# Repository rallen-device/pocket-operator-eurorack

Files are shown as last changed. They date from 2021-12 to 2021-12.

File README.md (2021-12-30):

# Pocket Operator Eurorack

Hardware for converting a teenage engineering pocket operator to be eurorack compatible.

Slots onto the back of the pocket operator. Requires soldering to the audio jacks + battery connectors.
Splits stereo input + output in two mono channels for each allowing separation of clock + audio.

Fits into a standard eurorack 3U case with width of 14HP.

# Relevant

3D step model of a pocket operator was created for this project. It can be found on grabcad: https://grabcad.com/library/teenage-engineering-pocket-operator-1

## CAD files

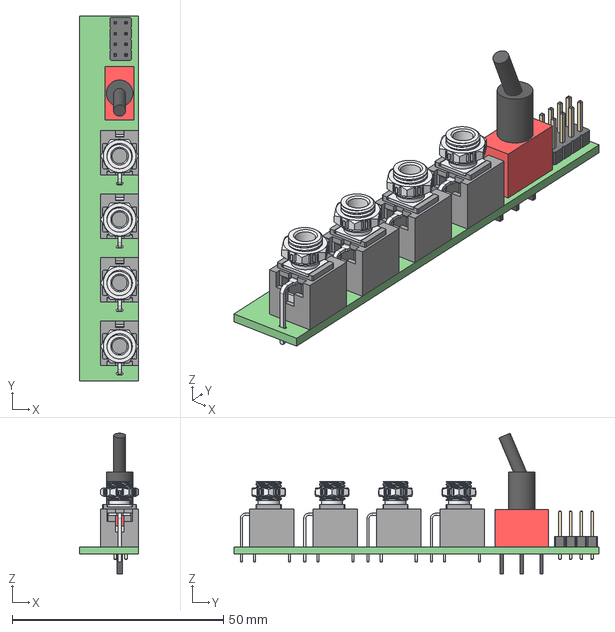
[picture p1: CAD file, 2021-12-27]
pocket-operator-eurorack-connector-board/pocket-operator-eurorack-connector-board.step
14.0 x 86.4 x 33.3 mm

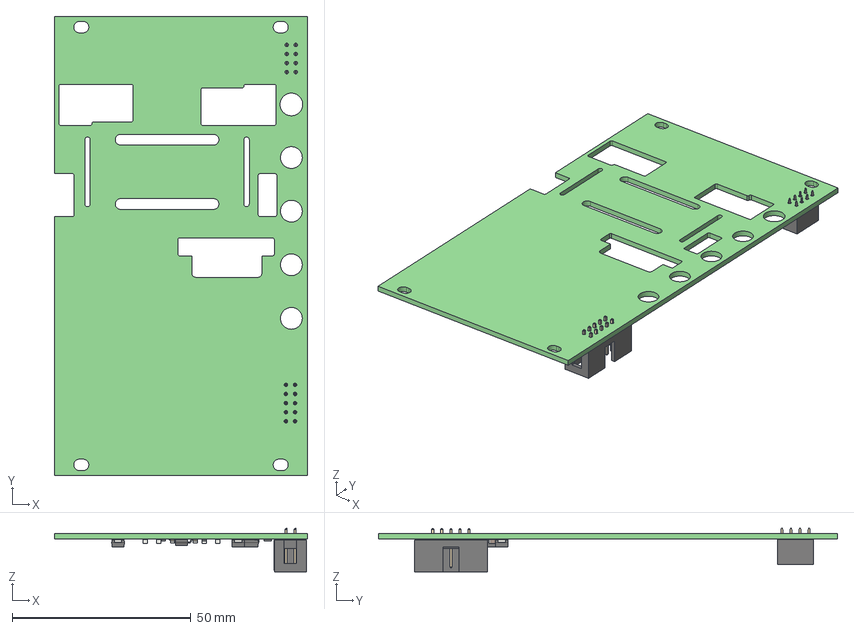
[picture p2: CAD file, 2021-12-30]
pocket-operator-eurorack/pocket-operator-eurorack.step
70.8 x 128.5 x 12.2 mm

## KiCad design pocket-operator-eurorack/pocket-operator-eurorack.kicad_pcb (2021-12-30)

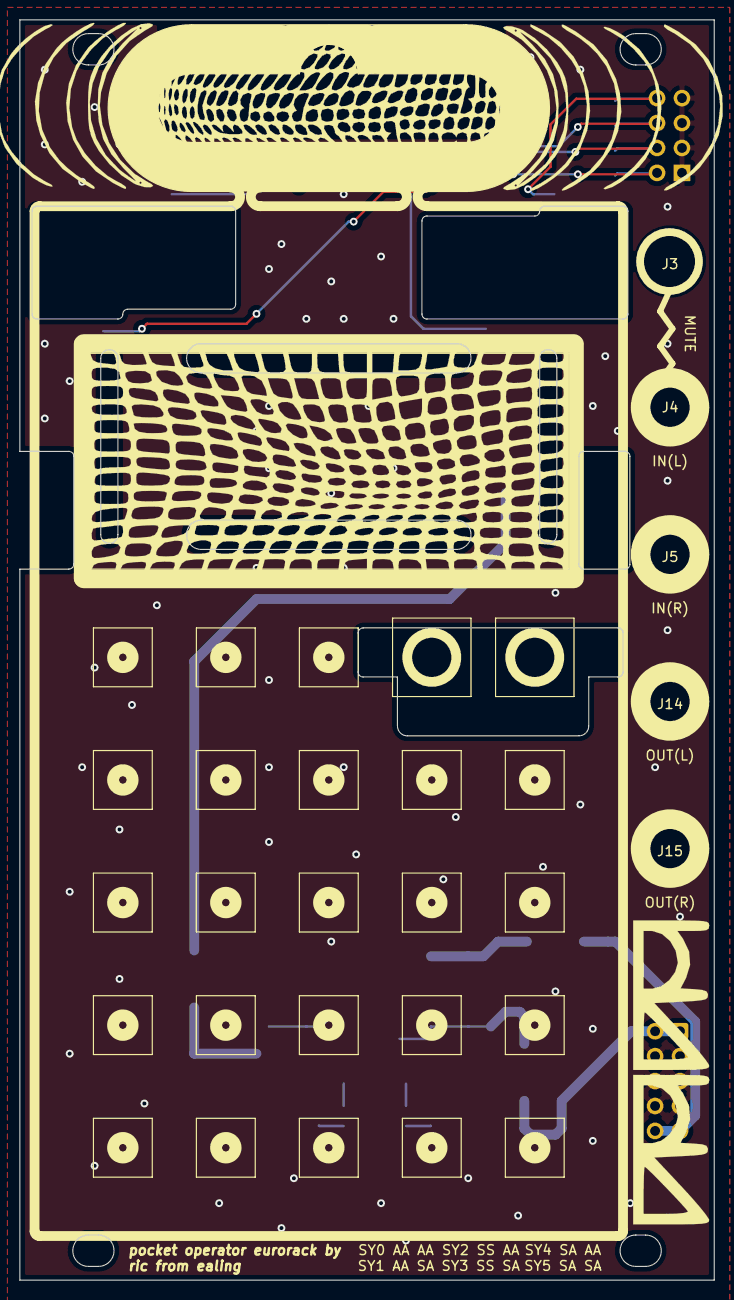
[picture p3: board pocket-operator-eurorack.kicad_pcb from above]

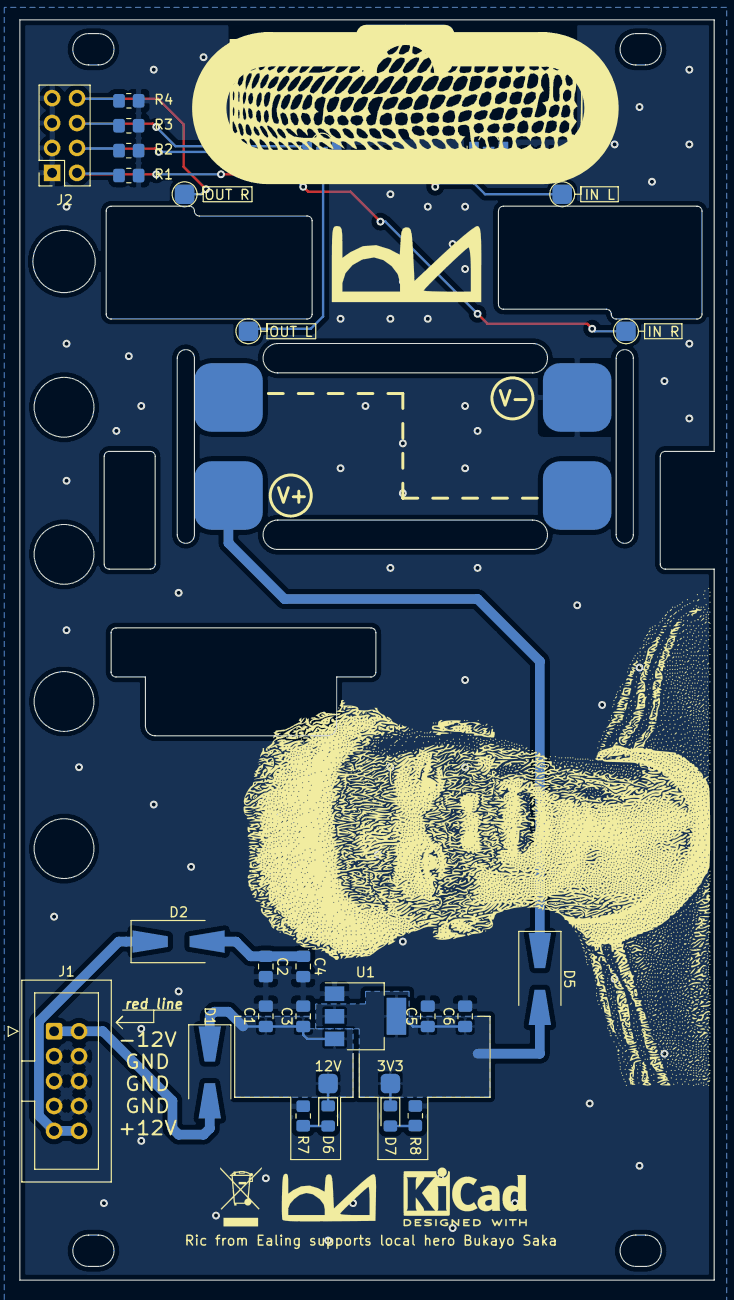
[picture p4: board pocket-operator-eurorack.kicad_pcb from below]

Board: 2 copper layers, 70.8 x 128.5 mm, 39 parts (34 on the bottom side), 15 nets.

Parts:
C1, C2, C3, C4, C5, C6: C; C_0805_2012Metric_Pad1.18x1.45mm_HandSolder
D1, D2, D5: D; D_SMA-SMB_Universal_Handsoldering
D3, D4: LED; LED_Kingbright_APFA3010_3x1.5mm_Horizontal
D6, D7: LED; LED_0805_2012Metric_Pad1.15x1.40mm_HandSolder
J1: Conn_02x05_Odd_Even; IDC-Header_2x05_P2.54mm_Vertical
J2: Conn_02x04_Odd_Even; PinSocket_2x04_P2.54mm_Vertical
J3: SW_6mm_panel
J4, J5, J14, J15: Thonkiconn_PJ398SM_panel
J6, J7, J8, J9, J16, J17: Conn_01x01; 2mm_solder_pad
J10, J11, J12, J13: Conn_01x01; 7mm_solder_pad
R1, R2, R3, R4, R5, R6, R7, R8: R; R_0805_2012Metric_Pad1.20x1.40mm_HandSolder
U1: NCP1117-3.3_SOT223; SOT-223-3_TabPin2

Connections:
+3V3: D5.1, J10.1
+12V: C1.1, C3.1, D1.1, D6.1, J16.1, U1.3
-12V: C2.1, C4.1, D2.2
/IN_L: D3.1, J2.2, J8.1, R1.1
/IN_R: J2.4, J6.1, R2.1
/OUT_L: D4.1, J2.6, J9.1, R3.1
/OUT_R: J2.8, J7.1, R4.1
GND: C1.2, C2.2, C3.2, C4.2, C5.2, C6.2, J1.3, J1.4, J1.5, J1.6, J1.7, J1.8, J2.1, J2.3, J2.5, J2.7, J11.1, R1.2, R2.2, R3.2, R4.2, R5.2, R6.2, R7.2, R8.2, U1.1
unnamed: C5.1, C6.1, D5.2, D7.1, J17.1, U1.2
unnamed: D1.2, J1.1, J1.2
unnamed: D2.1, J1.9, J1.10
unnamed: D3.2, R5.1
unnamed: D4.2, R6.1
unnamed: D6.2, R7.1
unnamed: D7.2, R8.1

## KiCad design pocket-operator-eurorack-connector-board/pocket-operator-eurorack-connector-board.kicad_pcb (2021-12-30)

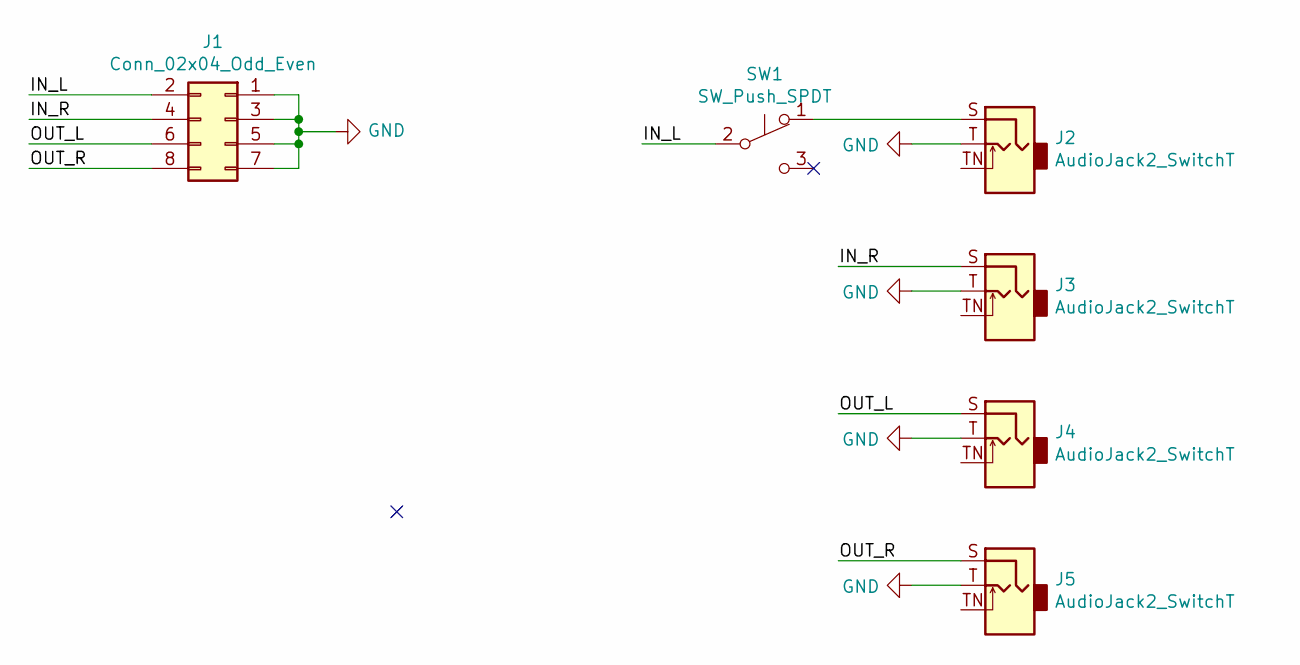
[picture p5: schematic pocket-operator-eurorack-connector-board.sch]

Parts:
J1: Conn_02x04_Odd_Even; PinHeader_2x04_P2.54mm_Vertical
J2, J3, J4, J5: AudioJack2_SwitchT; Jack_3.5mm_QingPu_WQP-PJ398SM_Vertical
SW1: SW_Push_SPDT; SW_6mm_SPDT

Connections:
/IN_L: J1.2, SW1.2 (B)
/IN_R: J1.4, J3.S
/OUT_L: J1.6, J4.S
/OUT_R: J1.8, J5.S
GND: J1.1, J1.3, J1.5, J1.7, J2.T, J3.T, J4.T, J5.T
unnamed: J2.S, SW1.1 (A)

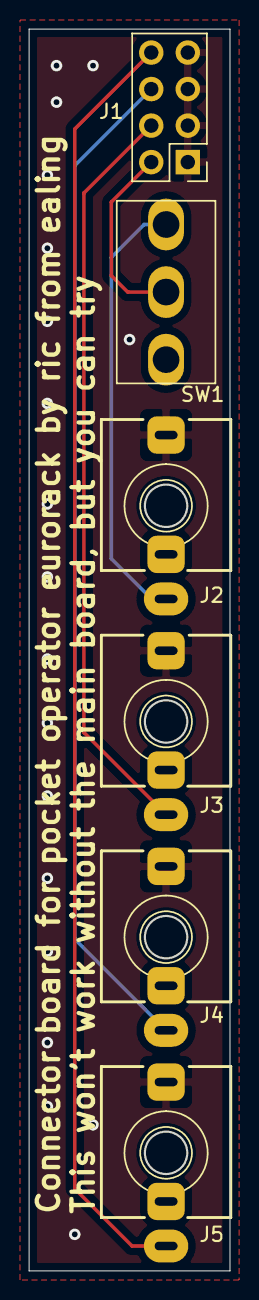
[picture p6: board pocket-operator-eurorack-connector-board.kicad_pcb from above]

Board: 2 copper layers, 14.0 x 86.4 mm, 6 parts (0 on the bottom side), 6 nets.

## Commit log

2021-12-26 update to kicad cut outs
    [pocket-operator-eurorack.kicad_pcb, pocket-operator-eurorack.sch]
2021-12-26 kicad silkscreen updated
    [pocket-operator-eurorack.kicad_pcb]
2021-12-26 front silkscreen artwork finished
    [pocket-operator-eurorack 3.sch, pocket-operator-eurorack.kicad_pcb, pocket-operator-eurorack.sch]
2021-12-27 components selected and placed on board, need to confirm that gnds are connector to each other and that in/out pads are placed correctly
    [pocket-operator-eurorack 3.kicad_pcb, pocket-operator-eurorack.kicad_pcb]
2021-12-27 all tracks tracked, everything added, ready to be reviewed
    [pocket-operator-eurorack.kicad_pcb, pocket-operator-eurorack.sch]
2021-12-27 connector board added, main board changed to fit connectors correctly
    [pocket-operator-eurorack-connector-board.kicad_pcb, pocket-operator-eurorack-connector-board.sch, pocket-operator-eurorack.kicad_pcb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]
2021-12-27 connector board placed and tracked
    [pocket-operator-eurorack-connector-board.kicad_pcb]
2021-12-27 connector board updated
    [pocket-operator-eurorack-connector-board.kicad_pcb]
2021-12-27 connector board finalised, ready for review
    [pocket-operator-eurorack-connector-board.kicad_pcb, pocket-operator-eurorack-connector-board.step, pocket-operator-eurorack.step]
2021-12-30 finished and gerbers sent off for production
    [pocket-operator-eurorack 4.kicad_pcb, pocket-operator-eurorack 4.sch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]
